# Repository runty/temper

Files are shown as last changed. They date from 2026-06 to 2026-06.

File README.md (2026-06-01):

# temper

This is a split, wireless-only mechanical keyboard fashioned after the [chocofi keyboard](https://github.com/pashutk/chocofi). It started as a simple modification of the original chocofi PCBs to include battery pads and power switches for wireless use, but in the end, I thought there were enough changes to warrant giving it a separate designation. However, this design remains compatible with chocofi cases and plates.

temper keyboard

## Features

- 36-key split keyboard with 3 rows x 5 columns + 3 thumb keys per half 
- Kailh choc spacing
- Sweep-like column stagger (with pinky columns 2 mm lower, like chocofi) with Corne-like thumb cluster
- Reversible PCB (so one design can be used for both halves)
- Kailh Choc v2 hotswap sockets and switches
- Intended to be used with [nice!nano](https://nicekeyboards.com/nice-nano)
- Uses 7-pin SPDT power switch and includes pads for battery on keyboard shield PCB
- Support for [nice!view](https://nicekeyboards.com/nice-view)
- Compatible with chocofi-style cases; switch plates need Choc v2-compatible cutouts

temper keyboard

## List of changes from original chocofi

- Add power switch
- Add solder pads for battery under ProMicro footprint
- Add footprint for a nice!view screen
- Switch out diode footprints for ones that have solder pads on both sides
- Switch ProMicro footprint for one that uses solder jumpers for cleaner design
- Remove TRRS jack
- Change reset switch out for one I could easily source from [Typeractive](https://www.typeractive.xyz)
- Rework KiCAD schematic for more pleasant development

## Bill of Materials

- 2x PCB (gerber files in [releases](https://github.com/raeedcho/temper/releases))
- 2x nice!nanos
- 2x LiPo batteries (see nice!nano documentation for suggestions)
- 2x Alps miniature SPDT switches
- 2x Panasonic miniature momentary button switches 
- 36x Kailh Choc v2 switches
- 36x Kailh Choc v2 hotswap sockets
- 36x Choc v2-compatible keycaps
- 36x 1N4148W SMD diodes
- (Technically optional but highly recommended) MCU socket:
  - 4x Mill-Max 310 series machine sockets
  - 48x Mill-Max pins for socketing microcontrollers
- (Optional) Minimal back plate case:
  - 2x 3mm acrylic back plate (SVG file for laser cutting in [case folder](case/temper-bottomplate.svg))
  - 10x M2 4 or 5mm brass standoffs (I used 5mm, but some users have said that 4mm fits better)
  - 20x M2 3mm screws
- (Optional) 2x FR-4 switch plate (goes well with the back plate--gerber files in [releases](https://github.com/raeedcho/temper/releases))
- (Optional) 2x nice!view screens

## Assembly

Assembly of this keyboard requires soldering the jumpers on the front-side of each PCB (underneath the microcontrollers). Past this, the assembly of this keyboard is similar to that of many other split wireless keyboards--there are many guides online to help. In case it helps with assembly, there's a screenshot of the PCB schematic in the somewhat incomplete [PCB folder readme](https://github.com/raeedcho/temper/tree/main/pcb).

Briefly, the full list of steps includes:

- Solder the jumpers underneath where the microcontrollers and battery would go (on PCB front). It's best to do this step first, since it's easiest when there are no other components on the board.
Soldered jumpers
- On PCB back:
  - Solder the diodes (ensuring diodes are oriented correctly--check diode schematic to match orientation to PCB)
  - Solder the switch sockets
- On PCB front:
  - Solder reset switch
  - Solder power switch
  - [Socket microcontroller](https://docs.splitkb.com/hc/en-us/articles/360011263059-How-do-I-socket-a-microcontroller-):
    - Solder sockets into PCB
    - Place masking tape (to divert solder from socket for next soldering step)
    - Insert Mill-Max pins or diode legs
    - Place microcontroller (blank side up)
    - Solder pins to microcontroller
    - Carefully remove microcontroller
    - Remove tape
  - (optional) socket nice!view displays (same procedure as socketing microcontroller)
  - *Carefully* solder battery wires to pads (ensuring wires don't short together--I used masking tape to secure wires)
  - Reseat microcontroller
- Putting it all together (follow specific case instructions if applicable)
  - (optional) For back plate:
    - attach standoffs to PCB with screws
    - slide PCB standoffs into the aligned backplate holes
    - secure backplate in place with M2 screws (the backplate will be sandwiched in place between the hot swap sockets and the screw heads)
  - If not using switch plate:
    - press switches directly into PCB sockets (ensuring switch legs make it into the sockets and don't bend out of the way)
  - If using switch plate:
    - press switches into plate
    - align switches with PCB holes and press into sockets (ensuring legs make it into sockets and don't bend out of the way)
  - Place keycaps on switches

## Firmware

This keyboard uses [ZMK firmware](https://zmk.dev), which allows for configuration through GitHub Actions. An example configuration repository is [here](https://github.com/raeedcho/temper-zmk-config.git). The temper has also been added as an outboard on [Miryoku ZMK](https://github.com/manna-harbour/miryoku_zmk) via this [pull request](https://github.com/manna-harbour/miryoku_zmk/pull/42).

## Case options

The temper should be compatible with any case that works on the chocofi. The pictures above show a minimal case using only a laser-cut acrylic backplate (SVG design [here](case/temper-bottomplate.svg)), held on by M2 screws and brass standoffs. It's also possible to add an FR-4 switch plate (KiCAD design [here](case/top-plate)), which helps keep the switches stable in the hot-swap sockets.

Other options:
- The [temper gasket case](https://github.com/calerouxz/TemperKB-case), designed specifically for the temper by [calerouxz](https://github.com/calerouxz). The gasket case is more complex than the simple acrylic backplate and FR-4 switch plate, but has a more polished final look and feel.
- This [custom temper case](https://github.com/AdrianBonpin/zmk-temper), designed by [AdrianBonpin](https://github.com/AdrianBonpin). This repository also contains another example firmware configuration, with support for [ZMK Studio](https://zmk.dev/docs/features/studio).
- A [CNC metal case](https://github.com/CoenTurk/temper-metal), designed by [CoenTurk](https://github.com/CoenTurk). See https://github.com/raeedcho/temper/pull/18 for images.

## Why "temper"?

Tempering is a finicky process that changes the structure of chocolate to make it more shiny, but doesn't really change the taste much.

Likewise, the changes I made to the chocofi didn't alter the original design much, but made some quality-of-life improvements for both development and my own personal aesthetics, at the cost of removing traditional wired operation and possibly making it more difficult to assemble, given the addition of many solder jumpers. 

## Resources

I adapted a few of the elements from these KiCAD libraries for use in this design:

- [chocofi](https://github.com/pashutk/chocofi) - The PCB switch layout came from the original chocofi design
- [kbd](https://github.com/foostan/kbd) - This library, by foostan, the designer of the popular Corne keyboard, provides useful schematic symbols and footprints
- [keyswitches.pretty](https://github.com/daprice/keyswitches.pretty) - library of switch footprints--especially useful for reversible PCBs.
- [swoop](https://github.com/jimmerricks/swoop) - Contains reversible PCB footprints for ProMicro pinout, OLED screens, and 7-pin power switches.

## Similar keyboards

There are many similar keyboards to this one and the chocofi, and I'm sure they've all taken inspiration from each other at one point or another. Here's a (surely incomplete) list:

- [Corne/crkbd](https://github.com/foostan/crkbd) - A popular column stagger, 42-key split keyboard with many variants
- [Cornish Zen](https://lowprokb.ca/collections/keyboards/products/corne-ish-zen) - A low-profile wireless redesign of the Corne with choc spacing, screens, and an aluminum case
- [Kyria](https://splitkb.com/collections/keyboard-kits/products/kyria-rev3-pcb-kit) - Another popular columns stagger, 50-key split keyboard, supporting rotary encoders. MX spacing only, but supports both MX and choc switches. More extreme column stagger on the pinky than the Corne. Large thumb cluster.
- [Ferris](https://github.com/pierrechevalier83/ferris) - Minimalistic 34-key split keyboard borrowing the pinky column stagger of the Kyria. MCU is soldered directly onto the board--not ProMicro pinout compatible.
- [Ferris Sweep](https://github.com/davidphilipbarr/Sweep) - Redesign of the Ferris for ProMicro MCU pinout, which also allows for a diodeless build. Many variations.
- [Swoop](https://github.com/jimmerricks/swoop) - Fork of the Ferris Sweep to add OLED screens and encoders
- [Urchin](https://github.com/duckyb/urchin) - Another fork of the Ferris Sweep to add support for nice!view screens, though with a traditional switch matrix and diodes.
- [Swept Corne](https://github.com/AYM1607/swept-crkbd) - A wireless-only mix between the Corne and Ferris Sweep--basically a choc-spaced Corne with the Kyria pinky stagger (or alternatively a choc-spaced Kyria with a Corne thumb cluster)
- [Phase](https://github.com/mjpauly/phase) - 42-key split keyboard--mix of the original Ferris and Corne.
- [Fifi](https://github.com/raychengy/fifi_split_keeb) - 36-key split keyboard. Basically an MX Ferris Sweep with a Corne thumb cluster
- [Chocofi](https://github.com/pashutk/chocofi) - Choc version of the Fifi. Stagger is like the Kyria and Ferris keyboards, but with the pinky column 2mm lower. The keyboard this repository was based on.
- [Roost](https://github.com/forrestbaer/roost) - Wireless-only Ferris Sweep with an extra thumb key per hand
- [TOTEM](https://github.com/GEIGEIGEIST/TOTEM) - 38 key split keyboard with Sweep-like column stagger. 3 thumb keys, like Corne, but also an extra pinky key. Also designed with finger splay for the ring and pinky fingers.
- [A. Dux](https://github.com/tapioki/cephalopoda/tree/main/Architeuthis%20dux) - 34-key split keyboard with aggressive column stagger and splay
- [KLOR](https://github.com/GEIGEIGEIST/KLOR) - Customizable split keyboard (via versatile break-off PCBs), with on-board MCU, encoders, and OLED screens

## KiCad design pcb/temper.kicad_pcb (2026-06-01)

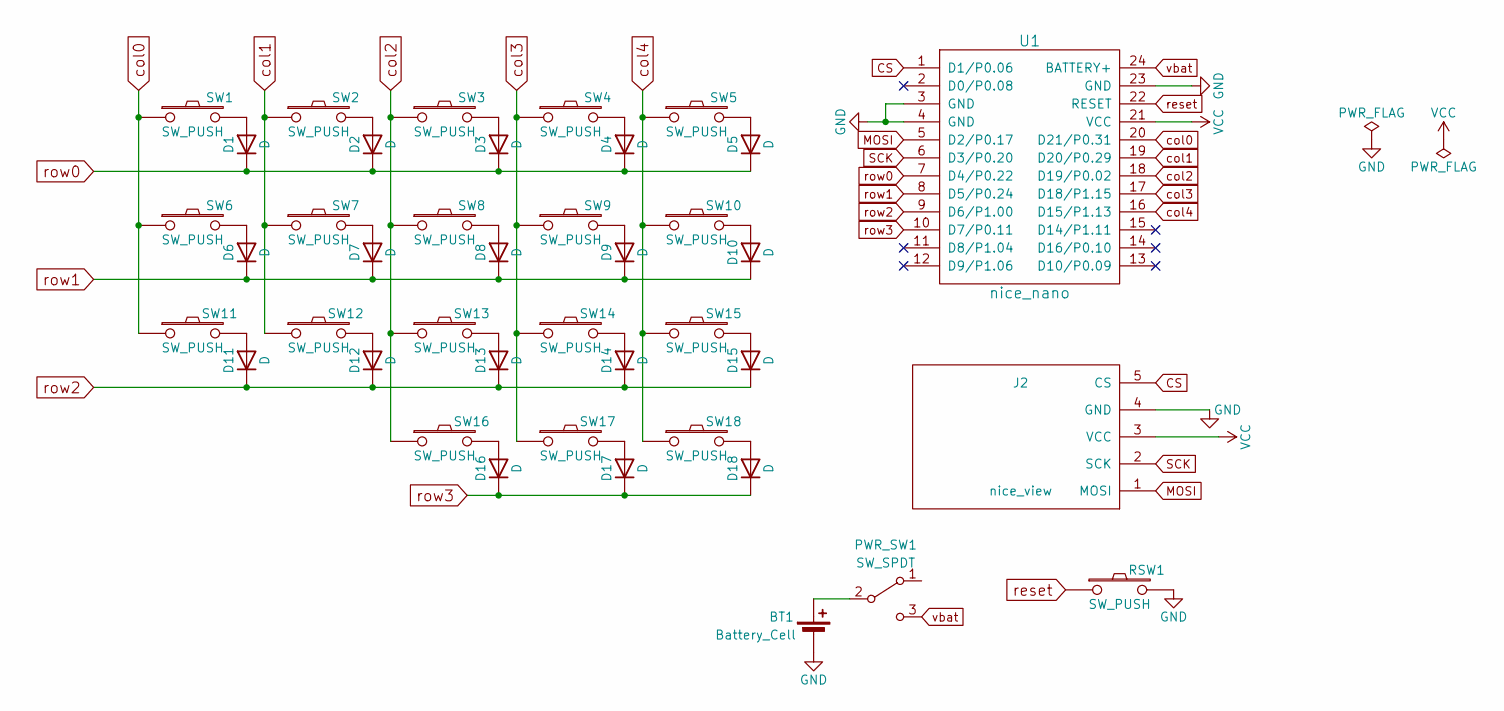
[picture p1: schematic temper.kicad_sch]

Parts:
BT1: Battery_Cell; Battery_pads_reversible
D1, D2, D3, D4, D5, D6, D7, D8, D9, D10, D11, D12, D13, D14, D15, D16, D17, D18: D; D_SMD_TH
J2: nice_view; nice_view_jumpers
PWR_SW1: SW_SPDT; power_switch_padreverse
RSW1: SW_PUSH; Panasonic_EVQPUL_EVQPUC_reversible
SW1: SW_PUSH; Kailh_socket_Choc_V2_reversible_edge_left_SW1
SW2: SW_PUSH; Kailh_socket_Choc_V2_reversible_edge_left_SW2
SW3, SW4, SW5, SW7, SW8, SW9, SW10, SW12, SW13, SW14, SW15: SW_PUSH; Kailh_socket_Choc_V2_reversible
SW6: SW_PUSH; Kailh_socket_Choc_V2_reversible_edge_left_SW6
SW11: SW_PUSH; Kailh_socket_Choc_V2_reversible_edge_both_SW11
SW16: SW_PUSH; Kailh_socket_Choc_V2_reversible_rot180_SW16
SW17: SW_PUSH; Kailh_socket_Choc_V2_reversible_rot165_SW17
SW18: SW_PUSH; Kailh_socket_Choc_V2_reversible_rot240_SW18
U1: nice_nano; ProMicro_jumpers

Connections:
CS: J2.5 (CS), U1.1 (D1/P0.06)
GND: BT1.2 (-), J2.4 (GND), RSW1.2, U1.3 (GND), U1.4 (GND), U1.23 (GND)
MOSI: J2.1 (MOSI), U1.5 (D2/P0.17)
unnamed: BT1.1 (+), PWR_SW1.2 (B)
unnamed: D1.2 (A), SW1.2
unnamed: D2.2 (A), SW2.2
unnamed: D3.2 (A), SW3.2
unnamed: D4.2 (A), SW4.2
unnamed: D5.2 (A), SW5.2
unnamed: D6.2 (A), SW6.2
unnamed: D7.2 (A), SW7.2
unnamed: D8.2 (A), SW8.2
unnamed: D9.2 (A), SW9.2
unnamed: D10.2 (A), SW10.2
unnamed: D11.2 (A), SW11.2
unnamed: D12.2 (A), SW12.2
unnamed: D13.2 (A), SW13.2
unnamed: D14.2 (A), SW14.2
unnamed: D15.2 (A), SW15.2
unnamed: D16.2 (A), SW16.2
unnamed: D17.2 (A), SW17.2
unnamed: D18.2 (A), SW18.2
SCK: J2.2 (SCK), U1.6 (D3/P0.20)
VCC: J2.3 (VCC), U1.21 (VCC)
col0: SW1.1, SW6.1, SW11.1, U1.20 (D21/P0.31)
col1: SW2.1, SW7.1, SW12.1, U1.19 (D20/P0.29)
col2: SW3.1, SW8.1, SW13.1, SW16.1, U1.18 (D19/P0.02)
col3: SW4.1, SW9.1, SW14.1, SW17.1, U1.17 (D18/P1.15)
col4: SW5.1, SW10.1, SW15.1, SW18.1, U1.16 (D15/P1.13)
reset: RSW1.1, U1.22 (RESET)
row0: D1.1 (K), D2.1 (K), D3.1 (K), D4.1 (K), D5.1 (K), U1.7 (D4/P0.22)
row1: D6.1 (K), D7.1 (K), D8.1 (K), D9.1 (K), D10.1 (K), U1.8 (D5/P0.24)
row2: D11.1 (K), D12.1 (K), D13.1 (K), D14.1 (K), D15.1 (K), U1.9 (D6/P1.00)
row3: D16.1 (K), D17.1 (K), D18.1 (K), U1.10 (D7/P0.11)
vbat: PWR_SW1.3 (C), U1.24 (BATTERY+)

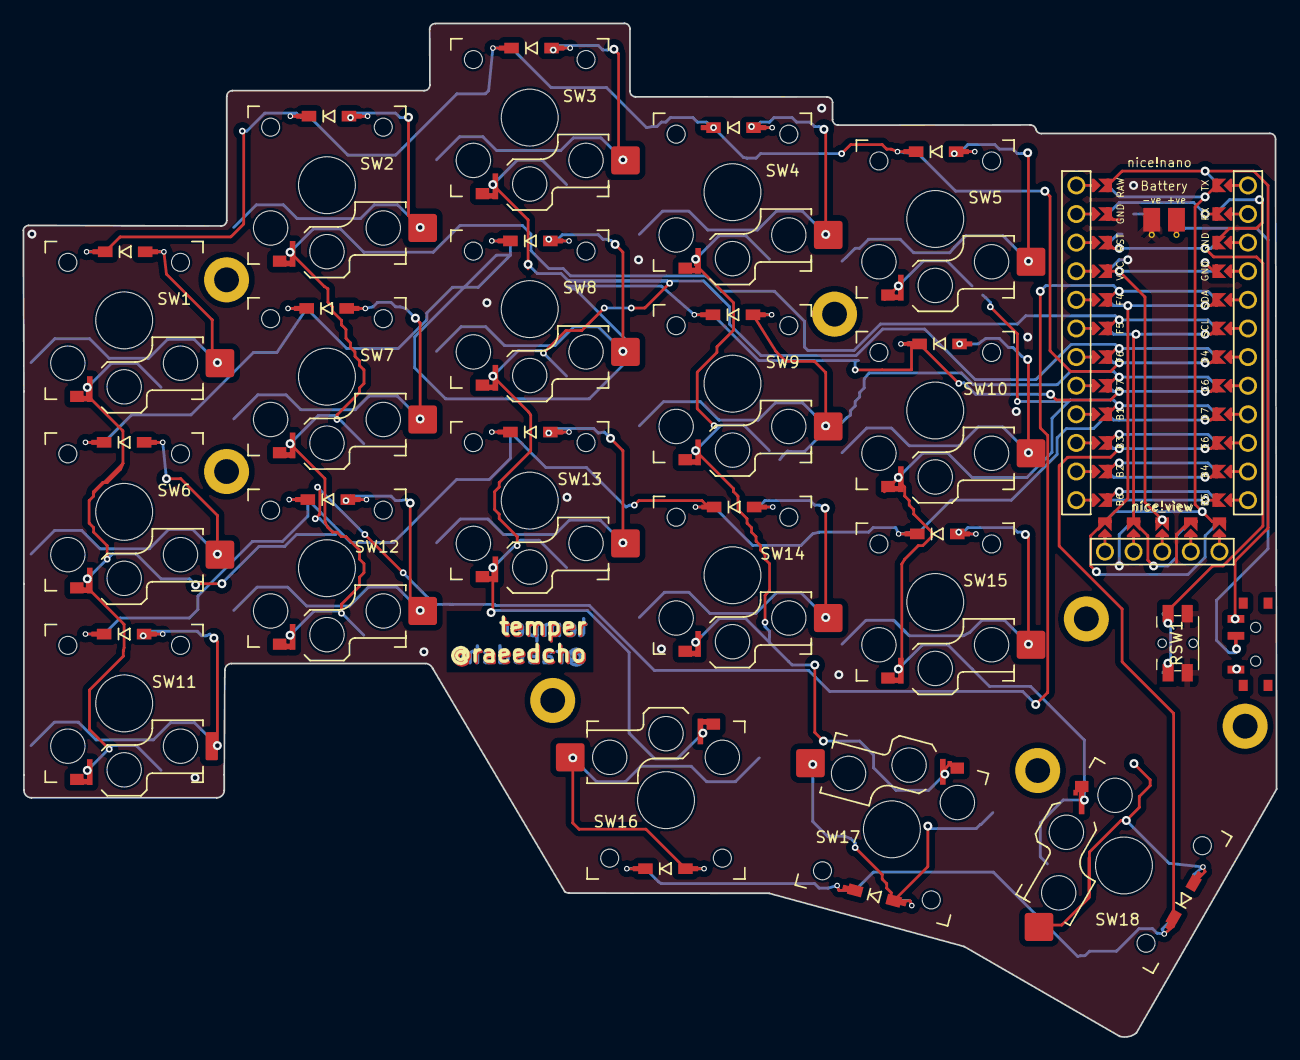
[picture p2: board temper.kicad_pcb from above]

Board: 2 copper layers, 111.3 x 90.0 mm, 48 parts (0 on the bottom side), 35 nets.

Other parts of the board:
H1: h1; LEGO_HOLE
h2: h2; LEGO_HOLE
h3: h3; LEGO_HOLE
h4: h4; LEGO_HOLE
h5: h5; LEGO_HOLE
h6: h6; LEGO_HOLE
h7: h7; LEGO_HOLE

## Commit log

2026-06-01 Convert switches to Choc v2 sockets
    [temper-topplate.kicad_pcb, temper.kicad_pcb, temper.kicad_sch]
2026-06-01 Clean up Choc v2 manufacturing files
    [temper.kicad_pcb, temper.kicad_sch]
